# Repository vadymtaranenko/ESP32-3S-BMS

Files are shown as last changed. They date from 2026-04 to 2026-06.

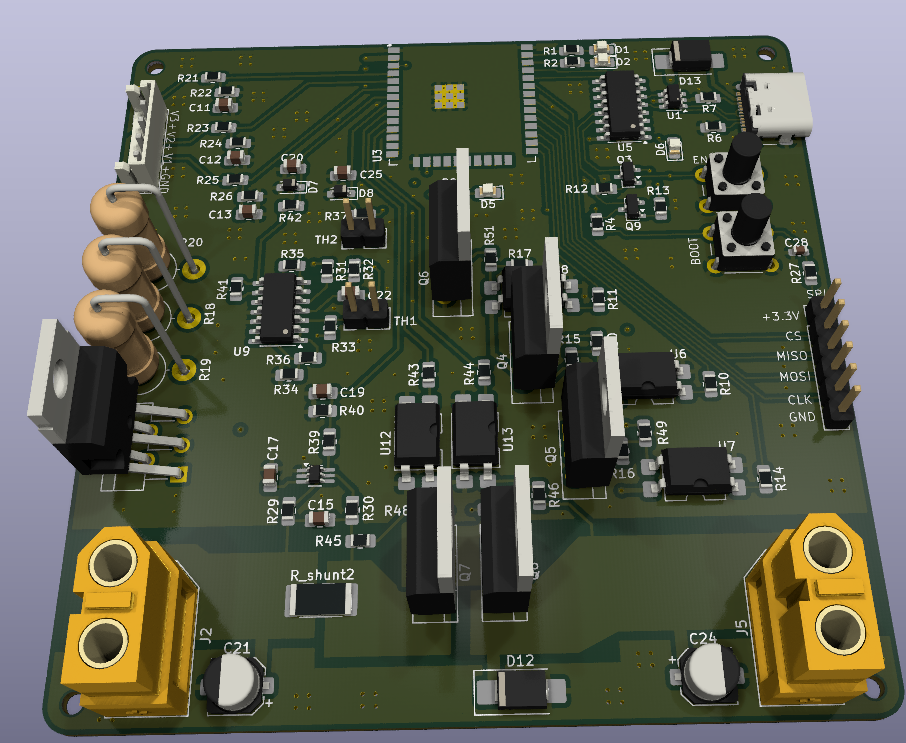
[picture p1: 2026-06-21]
Docs/Top.png

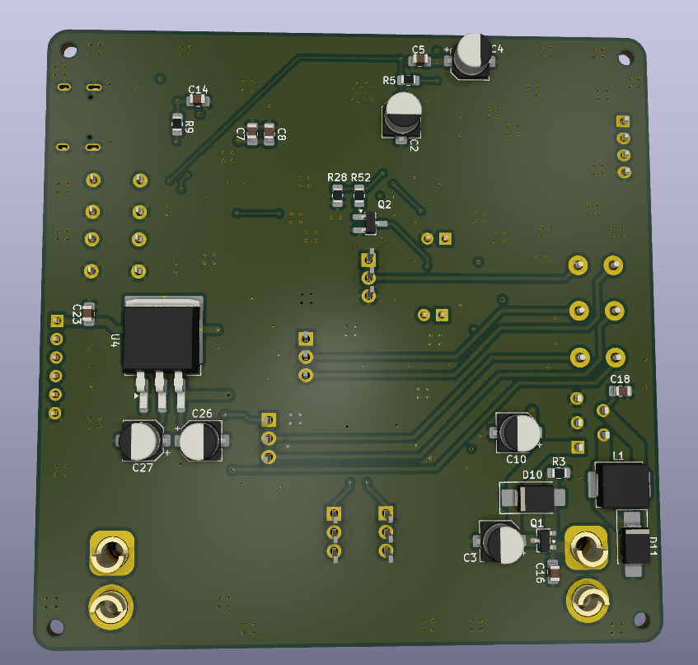
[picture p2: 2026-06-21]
Docs/Bottom.png

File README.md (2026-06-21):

#ESP32 3S BMS & Telemetry Node

Prosty, niezawodny system zarządzania pakietami Li-Po 3S oparty na mikrokontrolerze ESP32. Układ komunikuje się po magistrali SPI.

* **UVP / OVP (Under/Over-Voltage Protection):** Indywidualne monitorowanie napięcia każdej celi (domyślnie: min. 3.00 V, max. 4.20 V).
* **OCP (Over-Current Protection):** Ciągły pomiar poboru prądu pod obciążeniem (limit: 12.00 A).
* **OTP (Over-Temperature Protection):** Monitorowanie temperatury ogniw zapobiegające Thermal Runaway (limit: 50.0 °C).
* **Telemetria JSON:** Asynchroniczne wysyłanie ramek danych.

Specyfikacja Sprzętowa 

* **MCU:** ESP32-WROOM-32E (Moduł z Wi-Fi & Bluetooth, taktowanie do 240 MHz).
* **Zasilanie (Power Management):** Zintegrowana przetwornica Buck LM2596T-5 (obniżająca napięcie pakietu do 5V) oraz stabilizator LDO LD1086DT33TR (3.3V dla logiki). Wejście chronione przed odwrotną polaryzacją za pomocą P-MOSFETa.
* **Interfejs USB & Flash:** Złącze USB-C z zabezpieczeniem ESD (USBLC6-2SC6). Wbudowany konwerter USB-UART na układzie CH340C z obwodem Auto-Reset umożliwiającym płynne programowanie.
* **Pomiar Napięcia:** Indywidualny odczyt napięć na celach (V1+, V2+, V3+). Dzielniki rezystorowe załączane dynamicznie przez N-MOSFETy i separowane optoizolatorami (SFH617A), co całkowicie eliminuje problem samorozładowania pakietu.
* **Pomiar Prądu:** Pomiar na dedykowanym wzmacniaczu operacyjnym INA213 współpracującym z rezystorem bocznikowym (Shunt) 10 mΩ.
* **Pomiar Temperatury:** Dwutorowy układ pomiarowy: klasyczny termistor NTC oraz analogowy tor dla czujnika PT100 zrealizowany na układzie LM324.
* **Load Switch:** Sprzętowe odłączanie obciążenia (High-Side) realizowane za pomocą tranzystorów P-MOSFET IRF4905 sterowanych złączami optoizolowanymi.

##Struktura Repozytorium
* **`README.md`** - Główna dokumentacja projektu.
* **`/.gitignore`** - Reguły ignorowania plików tymczasowych (m m.in. KiCada i środowisk programistycznych).
* **`/Hardware`** - Pliki źródłowe projektu (schematy i projekt PCB) wykonane w programie KiCad.
* **`/Firmware`** - Kod źródłowy dla mikrokontrolera ESP32.
* **`/Docs`** - Dokumentacja dodatkowa (schematy w formacie PDF, rendery 3D).

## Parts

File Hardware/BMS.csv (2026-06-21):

Reference | Qty | Value | DNP | Exclude from BOM | Exclude from Board | Footprint | Datasheet
C2 | 1 | 100n |  |  |  | Capacitor_SMD:CP_Elec_5x4.5
C3,C21,C24 | 3 | 470u |  |  |  | Capacitor_SMD:CP_Elec_5x4.5
C4 | 1 | 22u |  |  |  | Capacitor_SMD:CP_Elec_5x4.5
C5,C7,C11,C12,C13,C14,C15,C16,C17,C18,C19,C20,C22,C23,C25 | 15 | 100n |  |  |  | Capacitor_SMD:C_0805_2012Metric_Pad1.18x1.45mm_HandSolder
C8 | 1 | 10u |  |  |  | Capacitor_SMD:C_0805_2012Metric_Pad1.18x1.45mm_HandSolder
C10 | 1 | 330u |  |  |  | Capacitor_SMD:CP_Elec_5x4.5
C26,C27 | 2 | 10u |  |  |  | Capacitor_SMD:CP_Elec_5x4.5
C28 | 1 | 100n |  |  |  | Capacitor_SMD:C_0603_1608Metric
D1,D2,D5 | 3 | RED |  |  |  | LED_SMD:LED_0805_2012Metric_Pad1.15x1.40mm_HandSolder
D6 | 1 | LED |  |  |  | LED_SMD:LED_0805_2012Metric_Pad1.15x1.40mm_HandSolder
D7,D8 | 2 | D_Zener |  |  |  | Diode_SMD:D_SOD-323_HandSoldering
D10,D11,D12,D13 | 4 | SS34 |  |  |  | Diode_SMD:D_SMB_Handsoldering | https://www.vishay.com/docs/88751/ss32.pdf
J1 | 1 | Conn_01x06_Pin |  |  |  | Connector_PinHeader_2.54mm:PinHeader_1x06_P2.54mm_Vertical
J2,J5 | 2 | Conn_01x02_Pin |  |  |  | Connector_AMASS:AMASS_XT60-F_1x02_P7.20mm_Vertical
J6 | 1 | Conn_01x04_Pin |  |  |  | Connector_JST:JST_EH_B4B-EH-A_1x04_P2.50mm_Vertical
J7 | 1 | USB_C_Receptacle_USB2.0_16P |  |  |  | Connector_USB:USB_C_Receptacle_GCT_USB4105-xx-A_16P_TopMnt_Horizontal | https://www.usb.org/sites/default/files/documents/usb_type-c.zip
L1 | 1 | 33u |  |  |  | Inductor_SMD:L_Panasonic_PCC-M0630M
Q1 | 1 | MMFTP3401-AQ |  |  |  | Package_TO_SOT_SMD:SOT-23-3 | https://ngspice.sourceforge.io/docs/ngspice-html-manual/manual.xhtml#cha_MOSFETs
Q2 | 1 | 2N7002 |  |  |  | Package_TO_SOT_SMD:SOT-23_Handsoldering | https://www.onsemi.com/pub/Collateral/NDS7002A-D.PDF
Q3,Q9 | 2 | SS8050 |  |  |  | Package_TO_SOT_SMD:SOT-23 | http://www.secosgmbh.com/datasheet/products/SSMPTransistor/SOT-23/SS8050.pdf
Q4,Q5,Q6 | 3 | IRLZ44N |  |  |  | Package_TO_SOT_THT:TO-220-3_Vertical | http://www.irf.com/product-info/datasheets/data/irlz44n.pdf
Q7,Q8 | 2 | IRF4905 |  |  |  | Package_TO_SOT_THT:TO-220-3_Vertical | http://www.infineon.com/dgdl/irf4905.pdf?fileId=5546d462533600a4015355e32165197c
R1,R2,R8,R42 | 4 | 1k |  |  |  | Resistor_SMD:R_0805_2012Metric_Pad1.20x1.40mm_HandSolder
R3,R5,R12,R13,R27,R37,R39,R40,R45,R46 | 10 | 10k |  |  |  | Resistor_SMD:R_0805_2012Metric_Pad1.20x1.40mm_HandSolder
R4,R31,R32,R33,R47,R48,R49,R50,R51,R52 | 10 | 100 |  |  |  | Resistor_SMD:R_0805_2012Metric_Pad1.20x1.40mm_HandSolder
R6,R7 | 2 | 5k1 |  |  |  | Resistor_SMD:R_0805_2012Metric_Pad1.20x1.40mm_HandSolder
R9 | 1 | 150 |  |  |  | Resistor_SMD:R_0805_2012Metric_Pad1.20x1.40mm_HandSolder
R10,R11,R14 | 3 | 150 |  |  |  | Resistor_SMD:R_0805_2012Metric_Pad1.20x1.40mm_HandSolder
R15,R16,R17,R28 | 4 | 3000 |  |  |  | Resistor_SMD:R_0805_2012Metric_Pad1.20x1.40mm_HandSolder
R18,R19,R20 | 3 | 16 |  |  |  | Resistor_THT:R_Axial_DIN0614_L14.3mm_D5.7mm_P5.08mm_Vertical
R21 | 1 | 300k |  |  |  | Resistor_SMD:R_0805_2012Metric_Pad1.20x1.40mm_HandSolder
R22,R24,R26,R36,R41 | 5 | 100k |  |  |  | Resistor_SMD:R_0805_2012Metric_Pad1.20x1.40mm_HandSolder
R23 | 1 | 200k |  |  |  | Resistor_SMD:R_0805_2012Metric_Pad1.20x1.40mm_HandSolder
R25 | 1 | 43k |  |  |  | Resistor_SMD:R_0805_2012Metric_Pad1.20x1.40mm_HandSolder
R29,R30 | 2 | 10 |  |  |  | Resistor_SMD:R_0805_2012Metric_Pad1.20x1.40mm_HandSolder
R34,R35 | 2 | 1k8 |  |  |  | Resistor_SMD:R_0805_2012Metric_Pad1.20x1.40mm_HandSolder
R43,R44 | 2 | 150 |  |  |  | Resistor_SMD:R_0805_2012Metric_Pad1.20x1.40mm_HandSolder
R_shunt2 | 1 | 10m |  |  |  | Resistor_SMD:R_2512_6332Metric_Pad1.40x3.35mm_HandSolder
SW3,SW4 | 2 | SW_Push |  |  |  | Button_Switch_THT:SW_PUSH_6mm_H9.5mm
TH1 | 1 | PT100 |  |  |  | Connector_PinHeader_2.54mm:PinHeader_1x02_P2.54mm_Vertical | https://www.heraeus.com/media/media/group/doc_group/products_1/hst/sot_to/de_15/to_92_d.pdf
TH2 | 1 | Thermistor_NTC |  |  |  | Connector_PinHeader_2.54mm:PinHeader_1x02_P2.54mm_Vertical
U1 | 1 | USBLC6-2SC6 |  |  |  | Package_TO_SOT_SMD:SOT-23-6 | https://www.st.com/resource/en/datasheet/usblc6-2.pdf
U2 | 1 | LM2596T-5 |  |  |  | Package_TO_SOT_THT:TO-220-5_P3.4x3.7mm_StaggerOdd_Lead3.8mm_Vertical | http://www.ti.com/lit/ds/symlink/lm2596.pdf
U3 | 1 | ESP32-WROOM-32E |  |  |  | RF_Module:ESP32-WROOM-32D | https://www.espressif.com/sites/default/files/documentation/esp32-wroom-32e_esp32-wroom-32ue_datasheet_en.pdf
U4 | 1 | LD1086DT33TR |  |  |  | Package_TO_SOT_SMD:TO-263-3_TabPin2 | https://www.st.com/resource/en/datasheet/ld1086.pdf
U5 | 1 | CH340C |  |  |  | Package_SO:SOIC-16_3.9x9.9mm_P1.27mm | https://datasheet.lcsc.com/szlcsc/Jiangsu-Qin-Heng-CH340C_C84681.pdf
U6,U7,U8,U12,U13 | 5 | SFH617A-3X007T |  |  |  | Package_DIP:SMDIP-4_W9.53mm_Clearance8mm | http://www.vishay.com/docs/83740/sfh617a.pdf
U9 | 1 | LM324 |  |  |  | Package_SO:SOIC-14_3.9x8.7mm_P1.27mm | http://www.ti.com/lit/ds/symlink/lm2902-n.pdf
U11 | 1 | INA213AIDCKT |  |  |  | Package_TO_SOT_SMD:SOT-363_SC-70-6_Handsoldering

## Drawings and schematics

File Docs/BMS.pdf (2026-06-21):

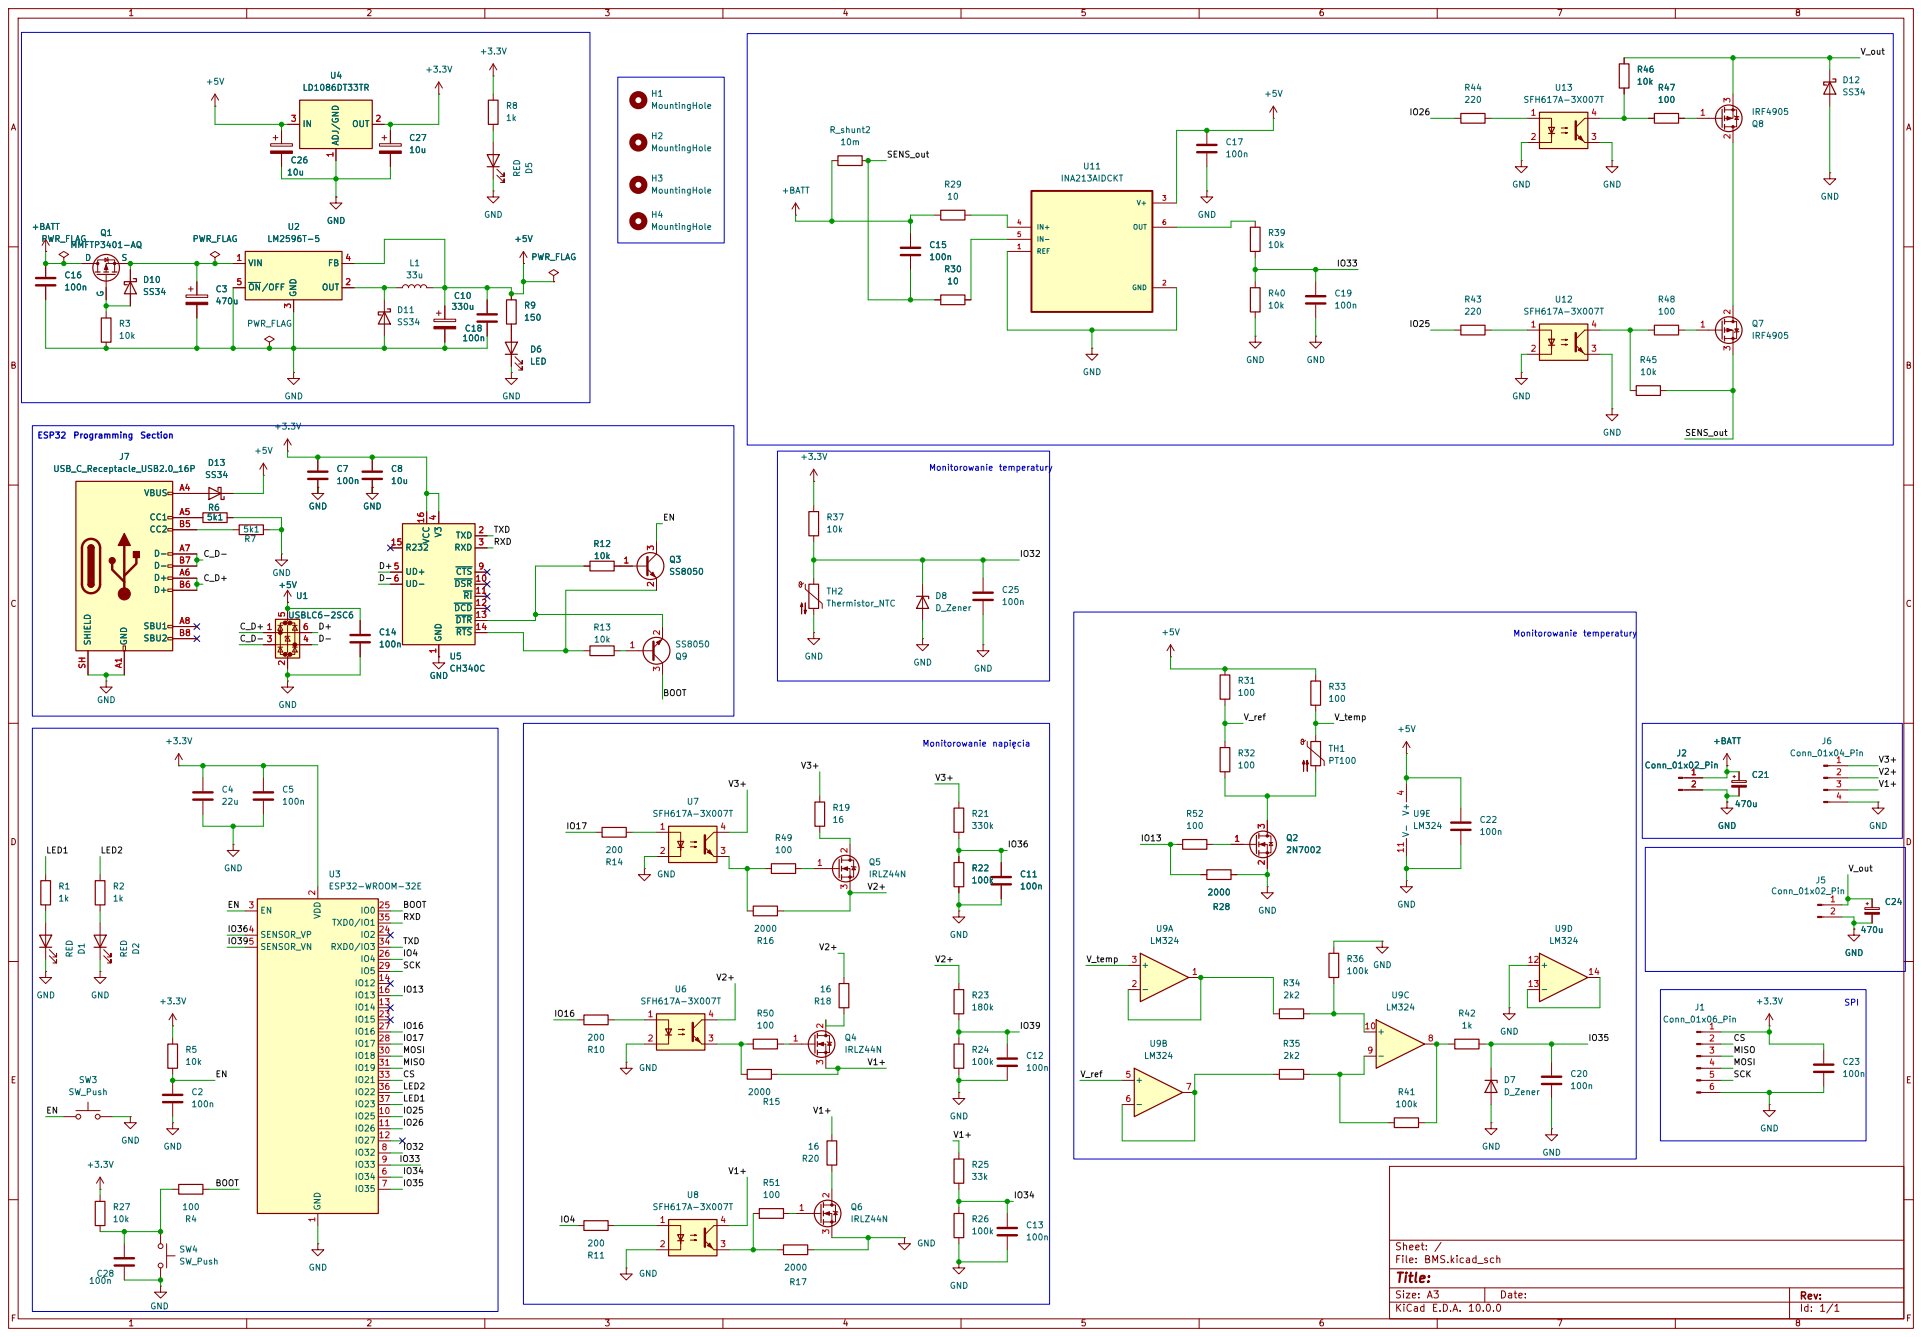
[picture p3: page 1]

4 UD+ 5 UD- 6 CTS 9 DSR 10 RI 11 DCD 12 DTR 13 RTS 14 R232 15 VCC 16 U5CH340C

4 UD+ 5 UD- 6 CTS 9 DSR 10 RI 11 DCD 12 DTR 13 RTS 14 R232 15 VCC 16 Q3

Size: A3 | Rev: | F Date:
KiCad E.D.A. 10.0.0 | Id: 1/1

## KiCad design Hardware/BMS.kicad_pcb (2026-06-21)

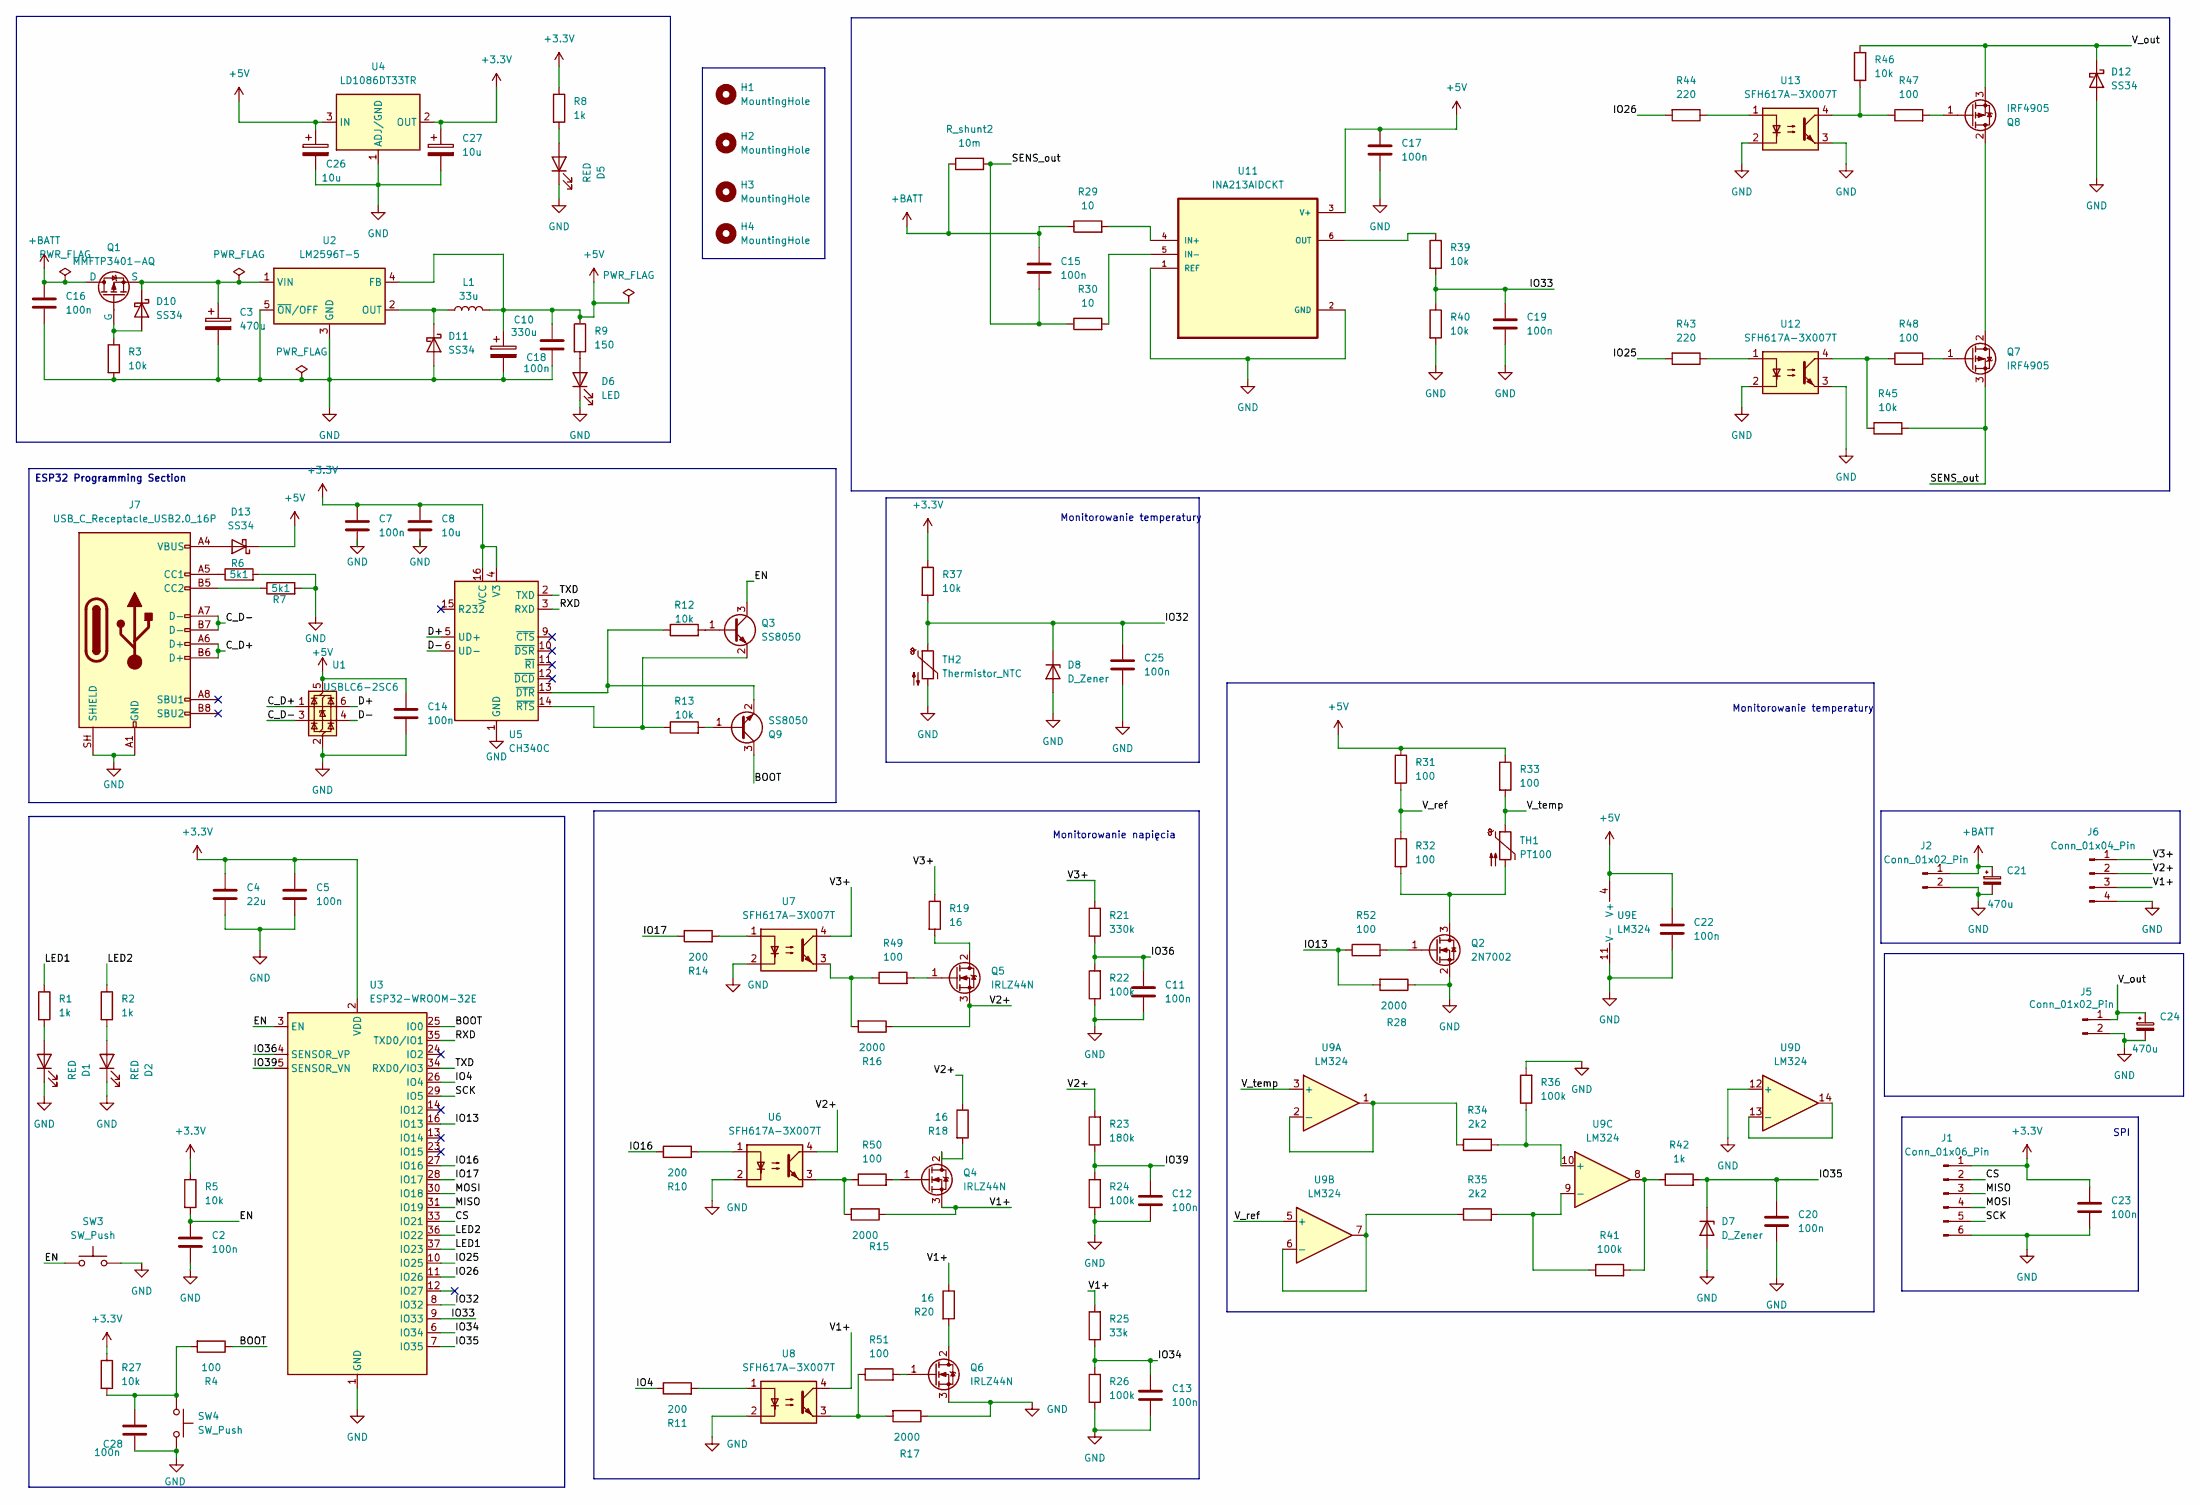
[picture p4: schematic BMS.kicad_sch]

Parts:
C2: 100n; CP_Elec_5x4.5
C3, C21, C24: 470u; CP_Elec_5x4.5
C4: 22u; CP_Elec_5x4.5
C5, C7, C11, C12, C13, C14, C15, C16, C17, C18, C19, C20, C22, C23, C25: 100n; C_0805_2012Metric_Pad1.18x1.45mm_HandSolder
C8: 10u; C_0805_2012Metric_Pad1.18x1.45mm_HandSolder
C10: 330u; CP_Elec_5x4.5
C26, C27: 10u; CP_Elec_5x4.5
C28: 100n; C_0603_1608Metric
D1, D2, D5: RED; LED_0805_2012Metric_Pad1.15x1.40mm_HandSolder
D6: LED; LED_0805_2012Metric_Pad1.15x1.40mm_HandSolder
D7, D8: D_Zener; D_SOD-323_HandSoldering
D10, D11, D12, D13: SS34; D_SMB_Handsoldering
H1, H2, H3, H4: MountingHole; MountingHole_2.2mm_M2_ISO7380
J1: Conn_01x06_Pin; PinHeader_1x06_P2.54mm_Vertical
J2, J5: Conn_01x02_Pin; AMASS_XT60-F_1x02_P7.20mm_Vertical
J6: Conn_01x04_Pin; JST_EH_B4B-EH-A_1x04_P2.50mm_Vertical
J7: USB_C_Receptacle_USB2.0_16P; USB_C_Receptacle_GCT_USB4105-xx-A_16P_TopMnt_Horizontal
L1: 33u; L_Panasonic_PCC-M0630M
Q1: MMFTP3401-AQ; SOT-23-3
Q2: 2N7002; SOT-23_Handsoldering
Q3, Q9: SS8050; SOT-23
Q4, Q5, Q6: IRLZ44N; TO-220-3_Vertical
Q7, Q8: IRF4905; TO-220-3_Vertical
R1, R2, R8, R42: 1k; R_0805_2012Metric_Pad1.20x1.40mm_HandSolder
R3, R5, R12, R13, R27, R37, R39, R40, R45, R46: 10k; R_0805_2012Metric_Pad1.20x1.40mm_HandSolder
R4, R31, R32, R33, R47, R48, R49, R50, R51, R52: 100; R_0805_2012Metric_Pad1.20x1.40mm_HandSolder
R6, R7: 5k1; R_0805_2012Metric_Pad1.20x1.40mm_HandSolder
R9: 150; R_0805_2012Metric_Pad1.20x1.40mm_HandSolder
R10, R11, R14: 200; R_0805_2012Metric_Pad1.20x1.40mm_HandSolder
R15, R16, R17, R28: 2000; R_0805_2012Metric_Pad1.20x1.40mm_HandSolder
R18, R19, R20: 16; R_Axial_DIN0614_L14.3mm_D5.7mm_P5.08mm_Vertical
R21: 330k; R_0805_2012Metric_Pad1.20x1.40mm_HandSolder
R22, R24, R26, R36, R41: 100k; R_0805_2012Metric_Pad1.20x1.40mm_HandSolder
R23: 180k; R_0805_2012Metric_Pad1.20x1.40mm_HandSolder
R25: 33k; R_0805_2012Metric_Pad1.20x1.40mm_HandSolder
R29, R30: 10; R_0805_2012Metric_Pad1.20x1.40mm_HandSolder
R34, R35: 2k2; R_0805_2012Metric_Pad1.20x1.40mm_HandSolder
R43, R44: 220; R_0805_2012Metric_Pad1.20x1.40mm_HandSolder
R_shunt2: 10m; R_2512_6332Metric_Pad1.40x3.35mm_HandSolder
SW3, SW4: SW_Push; SW_PUSH_6mm_H9.5mm
TH1: PT100; PinHeader_1x02_P2.54mm_Vertical
TH2: Thermistor_NTC; PinHeader_1x02_P2.54mm_Vertical
U1: USBLC6-2SC6; SOT-23-6
U2: LM2596T-5; TO-220-5_P3.4x3.7mm_StaggerOdd_Lead3.8mm_Vertical
U3: ESP32-WROOM-32E; ESP32-WROOM-32D
U4: LD1086DT33TR; TO-263-3_TabPin2
U5: CH340C; SOIC-16_3.9x9.9mm_P1.27mm
U6, U7, U8, U12, U13: SFH617A-3X007T; SMDIP-4_W9.53mm_Clearance8mm
U9: LM324; SOIC-14_3.9x8.7mm_P1.27mm
U11: INA213AIDCKT; SOT-363_SC-70-6_Handsoldering

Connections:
+3.3V: C4.1, C5.1, C7.1, C8.1, C23.1, C27.1, J1.1, R5.1, R8.1, R27.1, R37.1, U3.2 (VDD), U4.2 (OUT), U5.4 (V3), U5.16 (VCC)
+5V: C10.1, C14.1, C17.1, C18.1, C22.1, C26.1, D13.1 (K), L1.2, R9.1, R31.1, R33.1, U1.5 (VBUS), U2.4 (FB), U4.3 (IN), U9.4 (V+), U11.3 (V+)
+BATT: C15.1, C16.1, C21.1, J2.1, Q1.1 (D), R29.1, R_shunt2.1
/BOOT: Q9.3 (C), R4.1, U3.25 (IO0)
/CS: J1.2, U3.33 (IO21)
/C_D+: J7.A6 (D+), J7.B6 (D+), U1.1 (I/O1)
/C_D-: J7.A7 (D-), J7.B7 (D-), U1.3 (I/O2)
/D+: U1.6 (I/O1), U5.5 (UD+)
/D-: U1.4 (I/O2), U5.6 (UD-)
/EN: C2.1, Q3.3 (C), R5.2, SW3.1, U3.3 (EN)
/IO4: R11.1, U3.26 (IO4)
/IO13: R28.2, R52.1, U3.16 (IO13)
/IO16: R10.1, U3.27 (IO16)
/IO17: R14.1, U3.28 (IO17)
/IO25: R43.2, U3.10 (IO25)
/IO26: R44.2, U3.11 (IO26)
/IO32: C25.1, D8.1 (K), R37.2, TH2.1, U3.8 (IO32)
/IO33: C19.1, R39.2, R40.1, U3.9 (IO33)
/IO34: C13.1, R25.1, R26.2, U3.6 (IO34)
/IO35: C20.1, D7.1 (K), R42.2, U3.7 (IO35)
/IO36: C11.1, R21.1, R22.2, U3.4 (SENSOR_VP)
/IO39: C12.1, R23.1, R24.2, U3.5 (SENSOR_VN)
/LED1: R1.1, U3.37 (IO23)
/LED2: R2.1, U3.36 (IO22)
/MISO: J1.3, U3.31 (IO19)
/MOSI: J1.4, U3.30 (IO18)
/RXD: U3.35 (TXD0/IO1), U5.3 (RXD)
/SCK: J1.5, U3.29 (IO5)
/SENS_out: C15.2, Q7.3 (S), R30.1, R45.2, R_shunt2.2
/TXD: U3.34 (RXD0/IO3), U5.2 (TXD)
/V1+: J6.3, Q4.3 (S), R15.1, R20.1, R25.2, U8.4
/V2+: J6.2, Q5.3 (S), R16.1, R18.1, R23.2, U6.4
/V3+: J6.1, R19.1, R21.2, U7.4
/V_out: C24.1, D12.1 (K), J5.1, Q8.3 (S), R46.2
/V_ref: R31.2, R32.1, U9.5 (+)
/V_temp: R33.2, TH1.1, U9.3 (+)
GND: C2.2, C3.2, C4.2, C5.2, C7.2, C8.2, C10.2, C11.2, C12.2, C13.2, C14.2, C16.2, C17.2, C18.2, C19.2, C20.2, C21.2, C22.2, C23.2, C24.2, C25.2, C26.2, C27.2, C28.2, D1.1 (K), D2.1 (K), D5.1 (K), D6.1 (K), D7.2 (A), D8.2 (A), D11.2 (A), D12.2 (A), J1.6, J2.2, J5.2, J6.4, J7.A1 (GND), J7.A12 (GND), J7.B1 (GND), J7.B12 (GND), J7.SH (SHIELD), Q2.2 (S), Q6.3 (S), R3.2, R6.2, R7.2, R17.1, R22.1, R24.1, R26.1, R28.1, R36.2, R40.2, SW3.2, SW4.2, TH2.2, U1.2 (GND), U2.3 (GND), U2.5 (~ON/OFF), U3.1 (GND), U3.15 (GND), U3.38 (GND), U3.39 (GND), U4.1 (ADJ/GND), U5.1 (GND), U6.2, U7.2, U8.2, U9.11 (V-), U9.12 (+), U11.1 (REF), U11.2 (GND), U12.2, U12.3, U13.2, U13.3
unnamed: C28.1, R4.2, R27.2, SW4.1
unnamed: D1.2 (A), R1.2
unnamed: D2.2 (A), R2.2
unnamed: D5.2 (A), R8.2
unnamed: D6.2 (A), R9.2
unnamed: D10.2 (A), Q1.2 (G), R3.1
unnamed: C3.1, D10.1 (K), Q1.3 (S), U2.1 (VIN)
unnamed: D11.1 (K), L1.1, U2.2 (OUT)
unnamed: D13.2 (A), J7.A4 (VBUS), J7.A9 (VBUS), J7.B4 (VBUS), J7.B9 (VBUS)
unnamed: J7.A5 (CC1), R6.1
unnamed: J7.B5 (CC2), R7.1
unnamed: Q2.3 (D), R32.2, TH1.2
unnamed: Q2.1 (G), R52.2
unnamed: Q3.1 (B), R12.2
unnamed: Q3.2 (E), R13.1, U5.14 (~RTS)
unnamed: Q4.2 (D), R18.2
unnamed: Q4.1 (G), R50.2
unnamed: Q5.2 (D), R19.2
unnamed: Q5.1 (G), R49.2
unnamed: Q6.2 (D), R20.2
unnamed: Q6.1 (G), R51.2
unnamed: Q7.2 (D), Q8.2 (D)
unnamed: Q7.1 (G), R48.2
unnamed: Q8.1 (G), R47.2
unnamed: Q9.1 (B), R13.2
unnamed: Q9.2 (E), R12.1, U5.13 (~DTR)
unnamed: R10.2, U6.1
unnamed: R11.2, U8.1
unnamed: R14.2, U7.1
unnamed: R15.2, R50.1, U6.3
unnamed: R16.2, R49.1, U7.3
unnamed: R17.2, R51.1, U8.3
unnamed: R41.2, R42.1, U9.8
unnamed: R43.1, U12.1
unnamed: R44.1, U13.1
unnamed: R45.1, R48.1, U12.4
unnamed: R46.1, R47.1, U13.4
unnamed: R34.1, U9.1, U9.2 (-)
unnamed: R35.1, U9.6 (-), U9.7
unnamed: R34.2, R36.1, U9.10 (+)
unnamed: R35.2, R41.1, U9.9 (-)
unnamed: U9.13 (-), U9.14
unnamed: R29.2, U11.4 (IN+)
unnamed: R30.2, U11.5 (IN-)
unnamed: R39.1, U11.6 (OUT)

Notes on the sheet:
SPI
Monitorowanie temperatury
Monitorowanie napięcia
ESP32 Programming Section

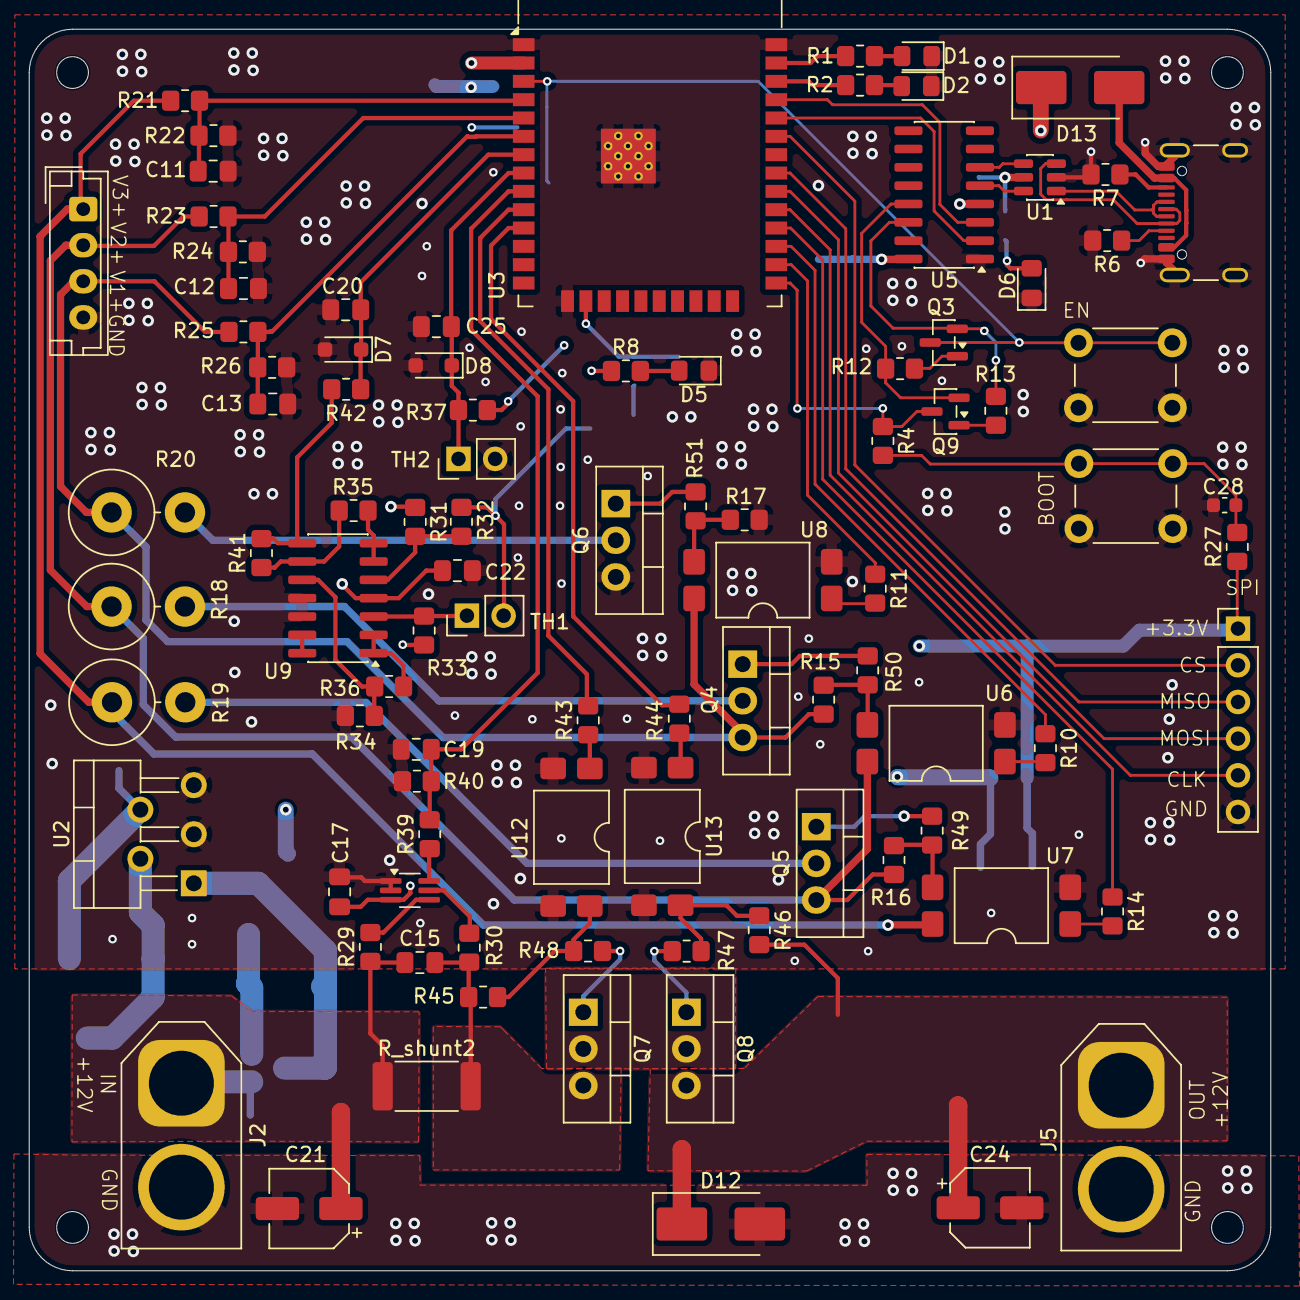
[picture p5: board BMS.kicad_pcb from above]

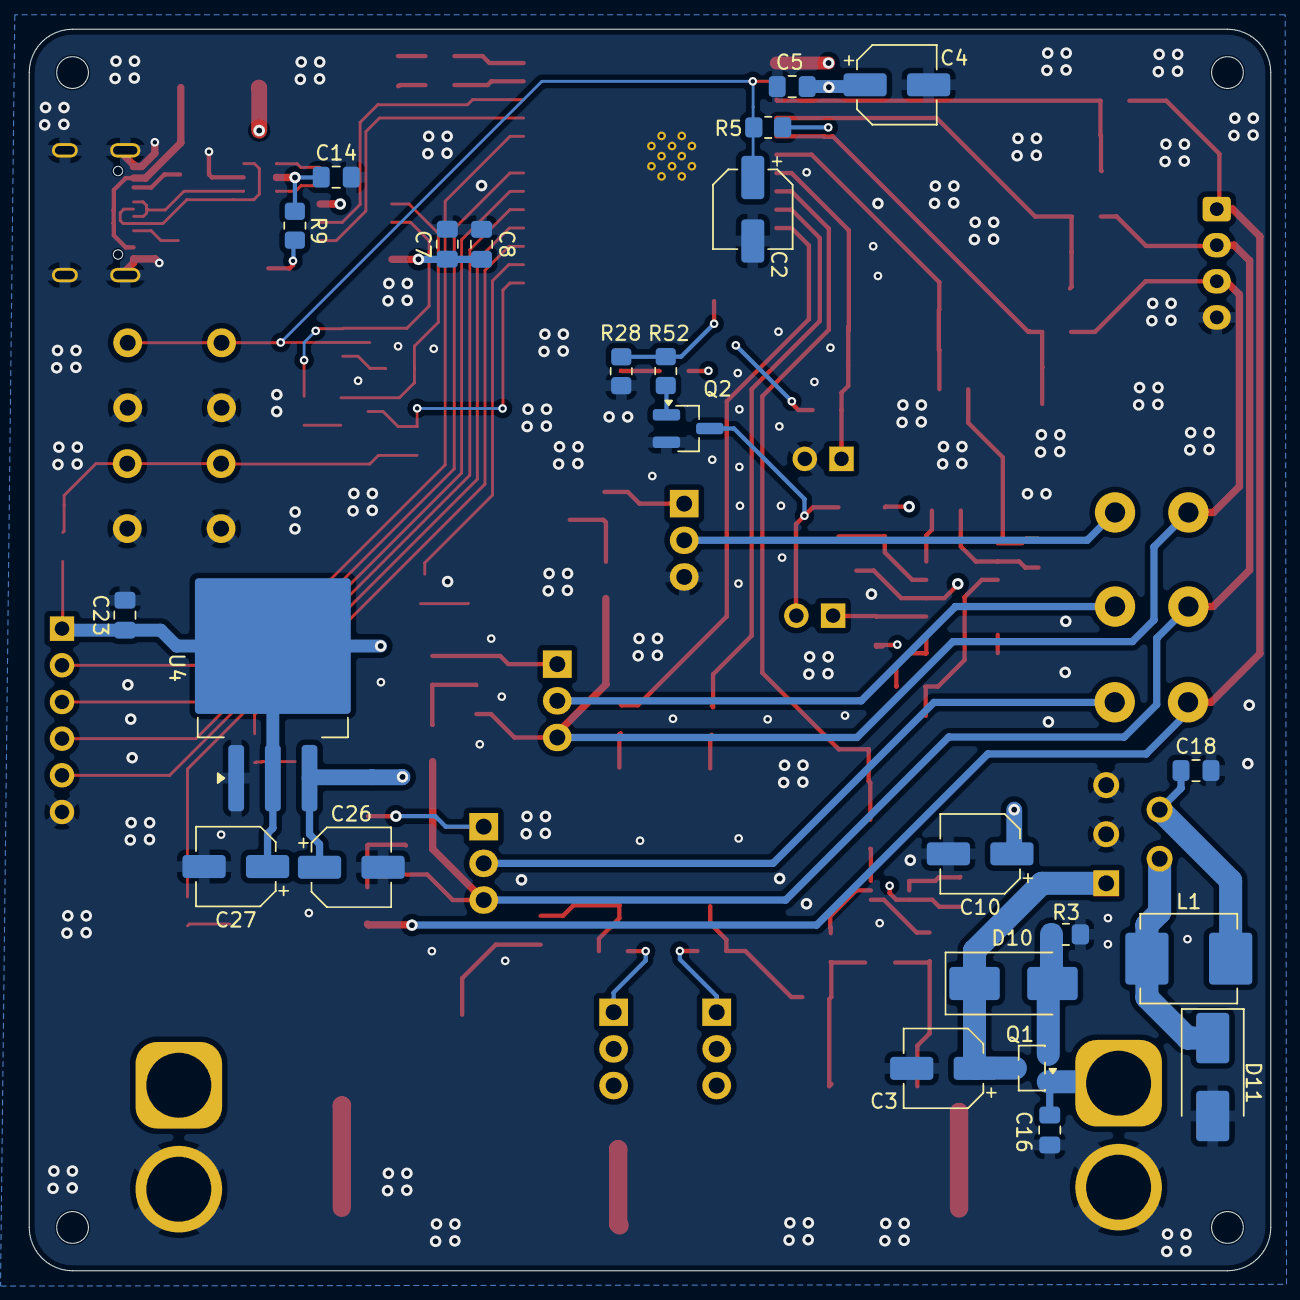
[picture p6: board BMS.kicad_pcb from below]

Board: 4 copper layers, 86.0 x 86.0 mm, 122 parts (24 on the bottom side), 82 nets.

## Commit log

2026-04-18 added foot_prints
    [BMS.kicad_pcb, BMS.kicad_sch]
2026-04-18 deklaracja warstw
    [BMS.kicad_pcb]
2026-04-18 pierwszy krok
    [BMS.kicad_pcb, BMS.kicad_sch]
2026-04-20 linki do TME
    [BMS.csv, BMS.kicad_pcb, BMS.kicad_sch]
2026-04-21 rezystory po 100 ohm do pt100
    [BMS.kicad_pcb, BMS.kicad_sch]
2026-04-21 Dodanie resystora do PT100
    [BMS.kicad_pcb, BMS.kicad_sch]
2026-04-28 rezystor V_out
    [BMS.csv, BMS.kicad_pcb, BMS.kicad_sch]
2026-04-28 poprawiłem
    [BMS.kicad_pcb, BMS.kicad_sch]
